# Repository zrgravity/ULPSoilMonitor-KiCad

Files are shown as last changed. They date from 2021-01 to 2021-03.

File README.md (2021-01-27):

# ULPSoilMonitor-KiCad

- Originally created by https://github.com/DerFlob
- See https://blog.m3k.cc/2021/01/ultra-low-power-soil-monitor/
- Original Git Repo: https://cgit.derflob.de/KiCad/ULPSoilMonitor.git
- Arduino source: https://github.com/zrgravity/ULPSoilMonitor-Arduino

Low Power Soil moisture monitor using off-the-shelf moisture sensors and ESP32. OSHW designed in KiCad and software in Arduino.

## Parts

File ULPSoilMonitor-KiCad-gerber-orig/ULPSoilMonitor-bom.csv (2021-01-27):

Comment | Designator | Footprint | LCSC
Battery | BT1 | flobs-KiCad-footprints:BatteryHolder_BHC-18650-1P-2P
470μF | C1 | Capacitor_SMD:CP_Elec_6.3x7.7 | C335982
22μF | C2 | Capacitor_SMD:C_0805_2012Metric | C45783
100nF | C3,C4,C7,C11,C12 | Capacitor_SMD:C_0805_2012Metric | C49678
4.7μF | C5,C6 | Capacitor_SMD:C_0805_2012Metric | C1779
47pF | C8,C9 | Capacitor_SMD:C_0805_2012Metric | C14857
CHARGING | D1 | LED_SMD:LED_0805_2012Metric | C84256
TX | D2 | LED_SMD:LED_0805_2012Metric | C84256
RX | D3 | LED_SMD:LED_0805_2012Metric | C2297
Conn_01x03_Male | J1,J2,J3,J4,J5,J6 | Connector_PinHeader_2.54mm:PinHeader_1x03_P2.54mm_Vertical
USB_B_Micro | J7 | Connector_USB:USB_Micro-B_Amphenol_10103594-0001LF_Horizontal
BME280_(GYBMEP) | J8 | Connector_PinHeader_2.54mm:PinHeader_1x04_P2.54mm_Vertical
BC807 | Q1 | Package_TO_SOT_SMD:SOT-23 | C8587
BC817 | Q3 | Package_TO_SOT_SMD:SOT-23 | C118725
MMDT3904 | Q2,Q4 | Package_TO_SOT_SMD:SOT-363_SC-70-6 | C155305
10k | R1,R21,R22 | Resistor_SMD:R_0805_2012Metric | C17414
4k7 | R2,R3 | Resistor_SMD:R_0805_2012Metric | C17673
27R | R19,R20 | Resistor_SMD:R_0805_2012Metric | C17594
1k | R23,R26 | Resistor_SMD:R_0805_2012Metric | C17513
3k9 | R15,R24 | Resistor_SMD:R_0805_2012Metric | C17614
2k37 | R25 | Resistor_SMD:R_0805_2012Metric | C17523
22k1 | R27 | Resistor_SMD:R_0805_2012Metric | C17518
47k5 | R28 | Resistor_SMD:R_0805_2012Metric | C26011
R | R29,R30 | Resistor_SMD:R_0805_2012Metric | C17630
68k | R4,R5,R6,R7,R12,R13,R14 | Resistor_SMD:R_0805_2012Metric | C17801
30k | R8,R9,R10,R11,R16,R17,R18 | Resistor_SMD:R_0805_2012Metric | C17621
RESET | SW1 | Button_Switch_SMD:SW_SPST_FSMSM | C354943
ESP32-WROOM-32 | U1 | RF_Module:ESP32-WROOM-32 | C473012
MCP73123 | U2 | Package_DFN_QFN:DFN-10-1EP_3x3mm_P0.5mm_EP1.65x2.38mm
CP2102N-A01-GQFN28 | U3 | Package_DFN_QFN:QFN-28-1EP_5x5mm_P0.5mm_EP3.35x3.35mm | C105167
BME280 | U4 | Package_LGA:Bosch_LGA-8_2.5x2.5mm_P0.65mm_ClockwisePinNumbering

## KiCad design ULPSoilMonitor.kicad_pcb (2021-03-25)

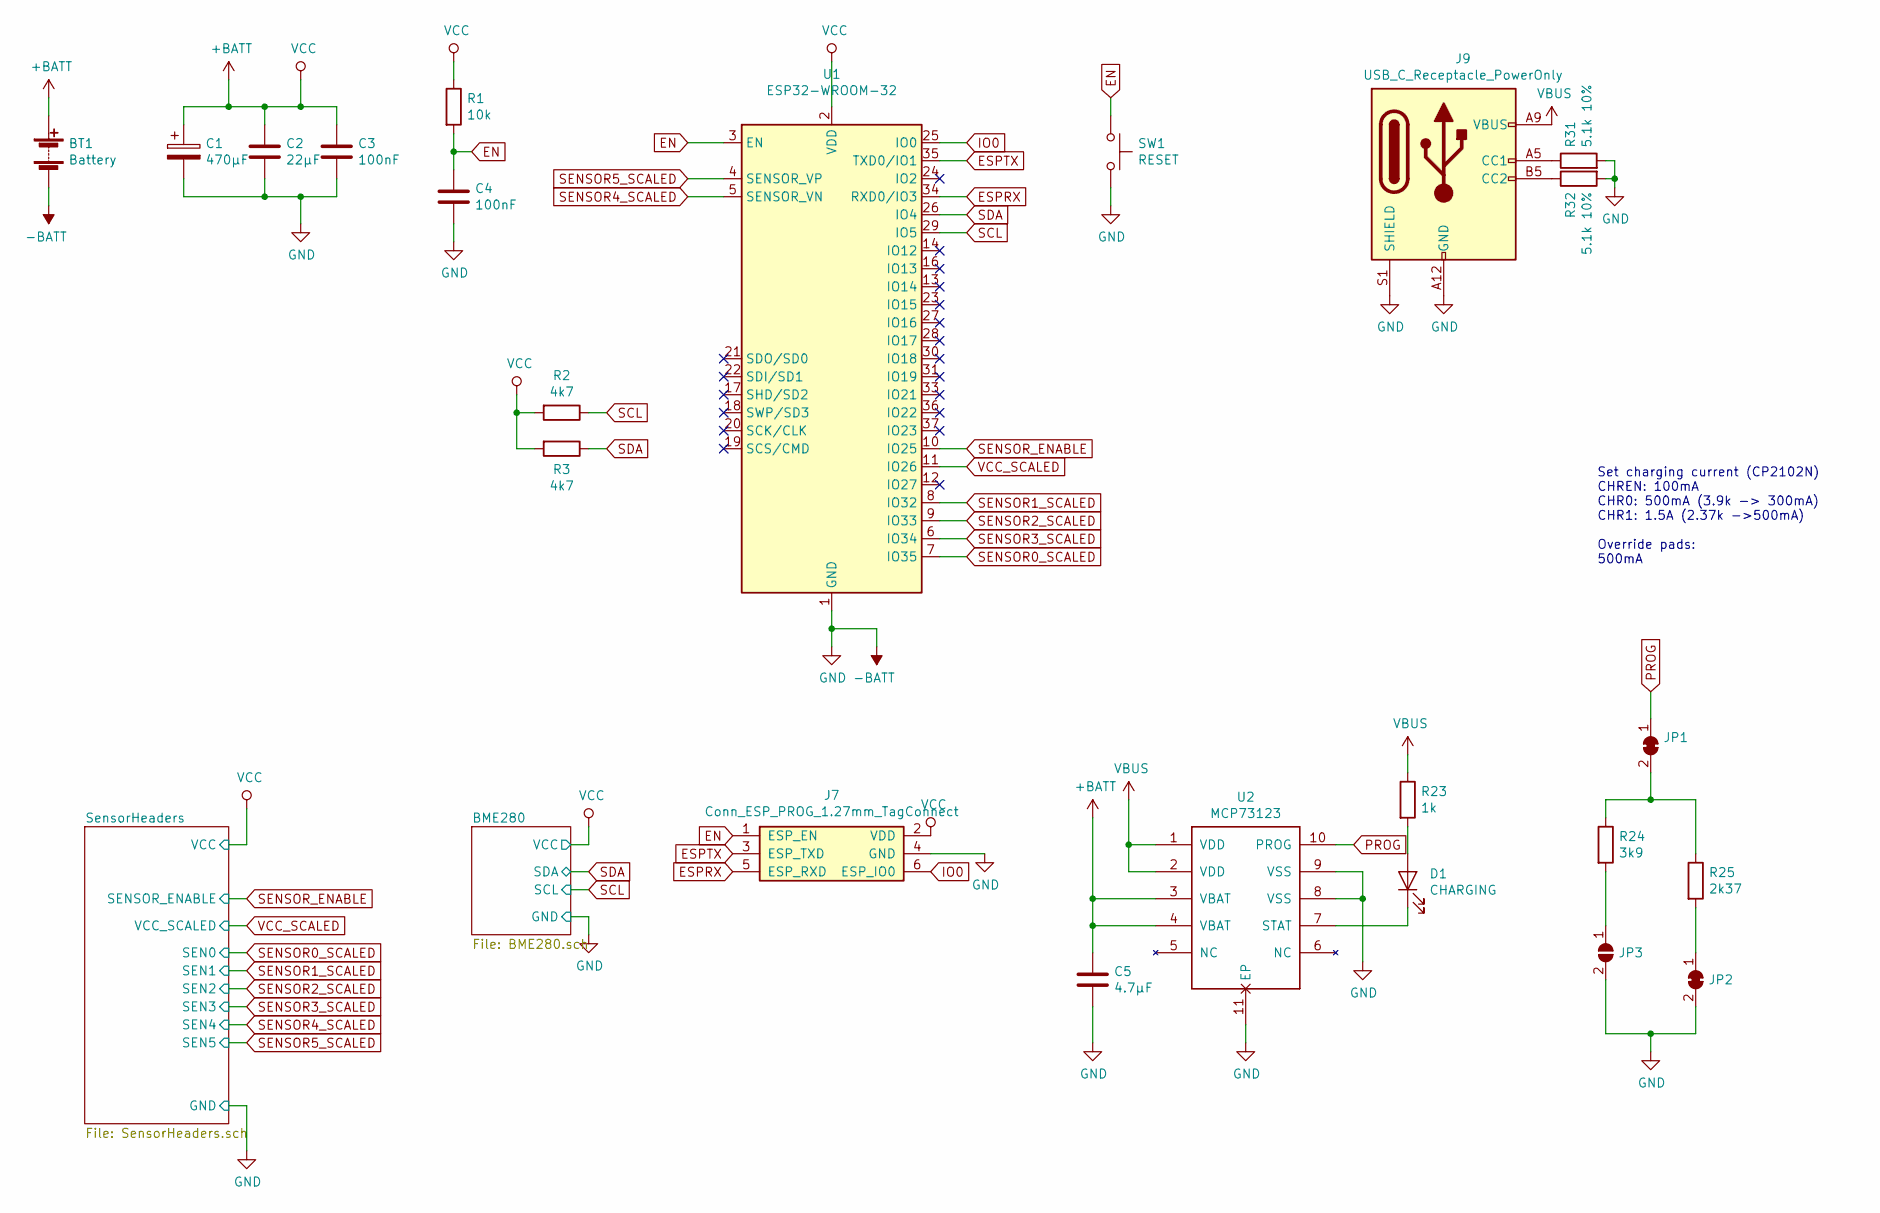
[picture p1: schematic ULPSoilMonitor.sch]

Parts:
BT1: Battery; BatteryHolder_BHC-18650-1P-2P
C1: 470μF; CP_Elec_6.3x7.7; LCSC C335982
C2: 22μF; C_0805_2012Metric; LCSC C45783
C3, C4: 100nF; C_0805_2012Metric; LCSC C49678
C5: 4.7μF; C_0805_2012Metric; LCSC C1779
D1: CHARGING; LED_0805_2012Metric; LCSC C84256
J7: Conn_ESP_PROG_1.27mm_TagConnect; Tag-Connect_TC2030-IDC-NL_2x03_P1.27mm_Vertical
J9: USB_C_Receptacle_PowerOnly; TYPE-C-31-M-17.kicad_mod
JP1: Charg_enable; SolderJumper-2_P1.3mm_Bridged_RoundedPad1.0x1.5mm
JP2: Charge_500mA; SolderJumper-2_P1.3mm_Bridged_RoundedPad1.0x1.5mm
JP3: Charge_300mA; SolderJumper-2_P1.3mm_Open_RoundedPad1.0x1.5mm
R1: 10k; R_0805_2012Metric; LCSC C17414
R2, R3: 4k7; R_0805_2012Metric; LCSC C17673
R23: 1k; R_0805_2012Metric; LCSC C17513
R24: 3k9; R_0805_2012Metric; LCSC C17614
R25: 2k37; R_0805_2012Metric; LCSC C17523
R31, R32: 5.1k 10%; R_0805_2012Metric; LCSC C17513
SW1: RESET; SW_SPST_FSMSM; LCSC C354943
U1: ESP32-WROOM-32; LCSC C473012
U2: MCP73123; DFN-10-1EP_3x3mm_P0.5mm_EP1.65x2.38mm

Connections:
+BATT: BT1.1 (+), C1.1, C2.1, C3.1, C5.1, J7.2 (VDD), R1.1, R2.2, R3.2, U1.2 (VDD), U2.3 (VBAT), U2.4 (VBAT); also elsewhere on the board
-BATT: BT1.2 (-), C1.2, C2.2, C3.2, C4.2, C5.2, J7.4 (GND), J9.A12 (GND), J9.B12 (GND), J9.S1 (SHIELD), JP2.2 (B), JP3.2 (B), R31.2, R32.2, SW1.2, U1.1 (GND), U1.15 (GND), U1.38 (GND), U1.39 (GND), U2.8 (VSS), U2.9 (VSS), U2.11 (EP); also elsewhere on the board
EN: C4.1, J7.1 (ESP_EN), R1.2, SW1.1, U1.3 (EN)
ESPRX: J7.5 (ESP_RXD), U1.34 (RXD0/IO3)
ESPTX: J7.3 (ESP_TXD), U1.35 (TXD0/IO1)
IO0: J7.6 (ESP_IO0), U1.25 (IO0)
unnamed: D1.1 (K), U2.7 (STAT)
unnamed: D1.2 (A), R23.2
unnamed: J9.A5 (CC1), R31.1
unnamed: J9.B5 (CC2), R32.1
unnamed: JP1.2 (B), R24.1, R25.1
unnamed: JP2.1 (A), R25.2
unnamed: JP3.1 (A), R24.2
PROG: JP1.1 (A), U2.10 (PROG)
SCL: R2.1, U1.29 (IO5); also elsewhere on the board
SDA: R3.1, U1.26 (IO4); also elsewhere on the board
SENSOR0_SCALED: U1.7 (IO35); also elsewhere on the board
SENSOR1_SCALED: U1.8 (IO32); also elsewhere on the board
SENSOR2_SCALED: U1.9 (IO33); also elsewhere on the board
SENSOR3_SCALED: U1.6 (IO34); also elsewhere on the board
SENSOR4_SCALED: U1.5 (SENSOR_VN); also elsewhere on the board
SENSOR5_SCALED: U1.4 (SENSOR_VP); also elsewhere on the board
SENSOR_ENABLE: U1.10 (IO25); also elsewhere on the board
VBUS: J9.A9 (VBUS), J9.B9 (VBUS), R23.1, U2.1 (VDD), U2.2 (VDD)
VCC_SCALED: U1.11 (IO26); also elsewhere on the board

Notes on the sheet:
Set charging current (CP2102N) CHREN: 100mA CHR0: 500mA (3.9k -> 300mA) CHR1: 1.5A (2.37k ->500mA) Override pads: 500mA

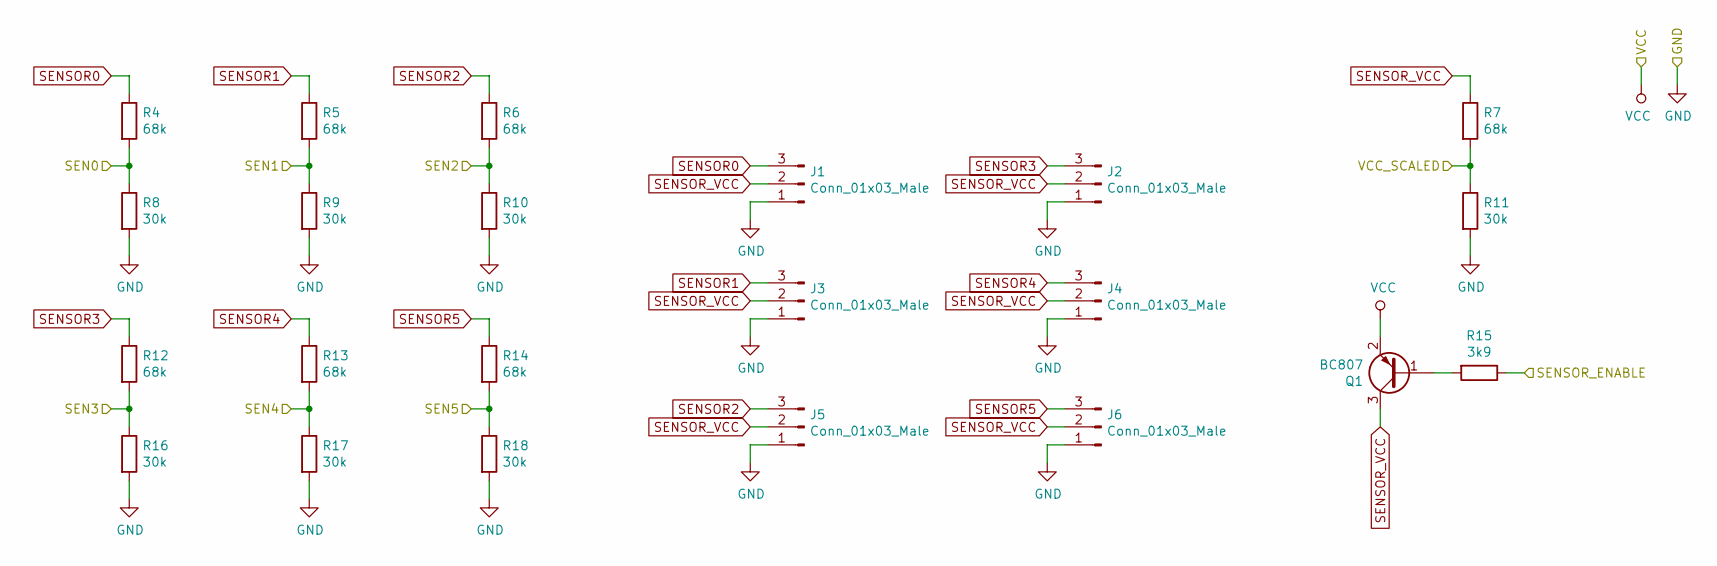
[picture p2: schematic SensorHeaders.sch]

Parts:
J1, J2, J3, J4, J5, J6: Conn_01x03_Male; PinHeader_1x03_P2.54mm_Vertical
Q1: BC807; SOT-23; LCSC C8587
R4, R5, R6, R7, R12, R13, R14: 68k; R_0805_2012Metric; LCSC C17801
R8, R9, R10, R11, R16, R17, R18: 30k; R_0805_2012Metric; LCSC C17621
R15: 3k9; R_0805_2012Metric; LCSC C17614

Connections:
+BATT: Q1.2 (E); also elsewhere on the board
-BATT: J1.1, J2.1, J3.1, J4.1, J5.1, J6.1, R8.2, R9.2, R10.2, R11.2, R16.2, R17.2, R18.2; also elsewhere on the board
unnamed: Q1.1 (B), R15.2
SENSOR0: J1.3, R4.1
SENSOR0_SCALED: R4.2, R8.1; also elsewhere on the board
SENSOR1: J3.3, R5.1
SENSOR1_SCALED: R5.2, R9.1; also elsewhere on the board
SENSOR2: J5.3, R6.1
SENSOR2_SCALED: R6.2, R10.1; also elsewhere on the board
SENSOR3: J2.3, R12.1
SENSOR3_SCALED: R12.2, R16.1; also elsewhere on the board
SENSOR4: J4.3, R13.1
SENSOR4_SCALED: R13.2, R17.1; also elsewhere on the board
SENSOR5: J6.3, R14.1
SENSOR5_SCALED: R14.2, R18.1; also elsewhere on the board
SENSOR_ENABLE: R15.1; also elsewhere on the board
SENSOR_VCC: J1.2, J2.2, J3.2, J4.2, J5.2, J6.2, Q1.3 (C), R7.1
VCC_SCALED: R7.2, R11.1; also elsewhere on the board

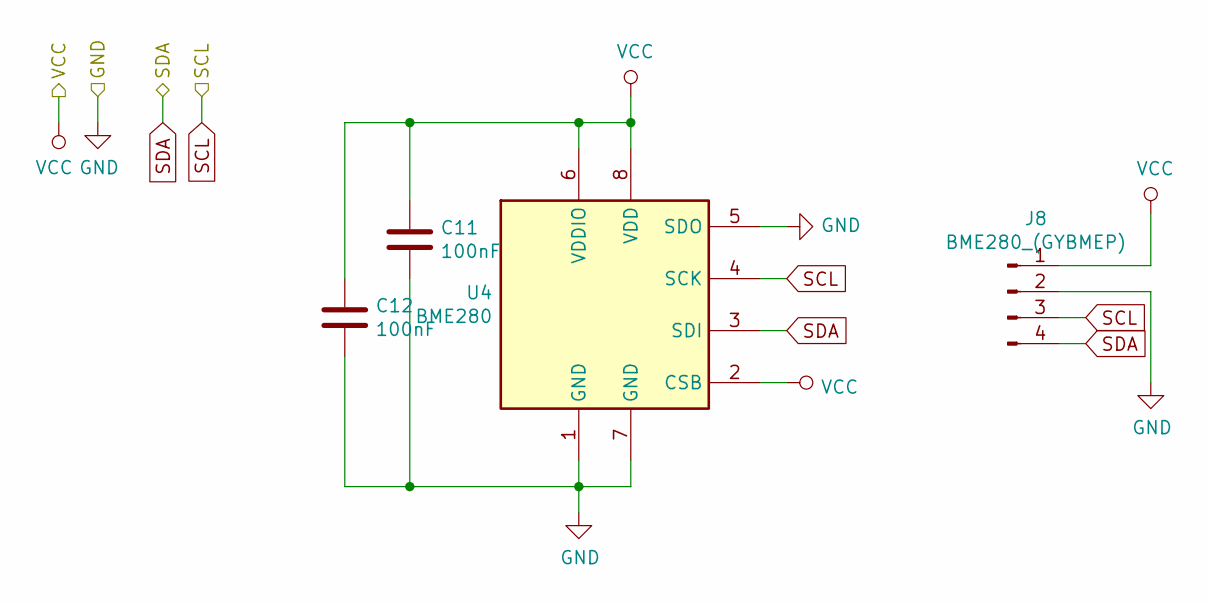
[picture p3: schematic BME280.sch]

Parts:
C11, C12: 100nF; C_0805_2012Metric; LCSC C49678
J8: BME280_(GYBMEP); PinHeader_1x04_P2.54mm_Vertical
U4: BME280; Bosch_LGA-8_2.5x2.5mm_P0.65mm_ClockwisePinNumbering

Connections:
+BATT: C11.1, C12.1, J8.1, U4.2 (CSB), U4.6 (VDDIO), U4.8 (VDD); also elsewhere on the board
-BATT: C11.2, C12.2, J8.2, U4.1 (GND), U4.5 (SDO), U4.7 (GND); also elsewhere on the board
SCL: J8.3, U4.4 (SCK); also elsewhere on the board
SDA: J8.4, U4.3 (SDI); also elsewhere on the board

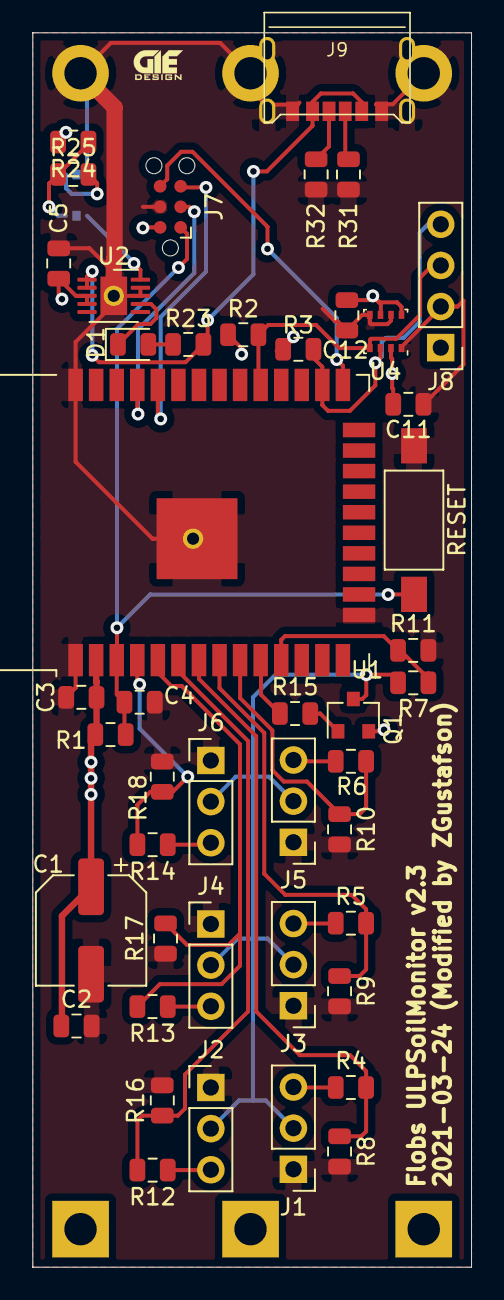
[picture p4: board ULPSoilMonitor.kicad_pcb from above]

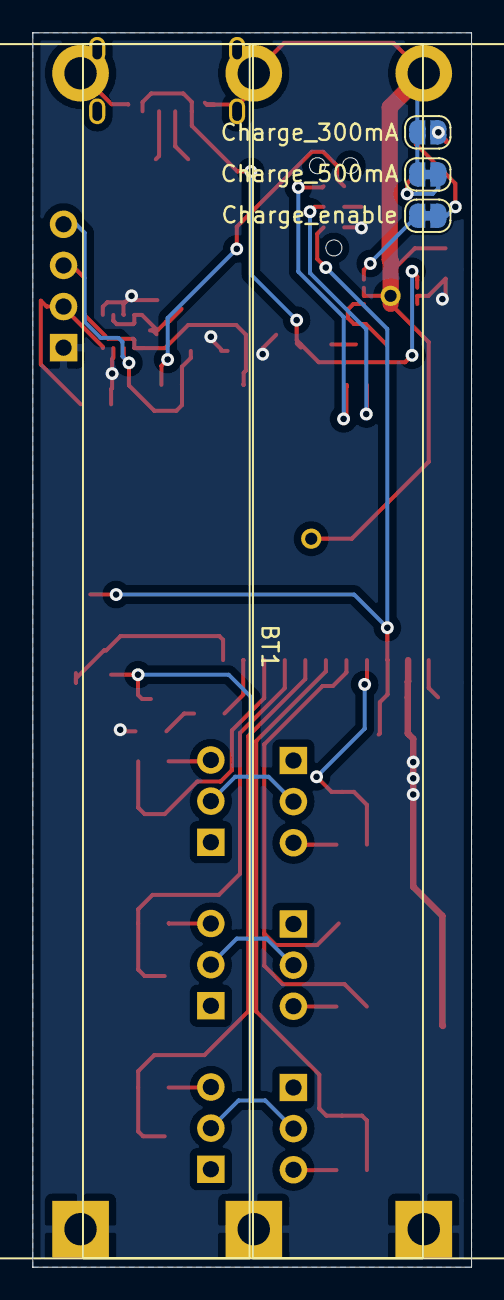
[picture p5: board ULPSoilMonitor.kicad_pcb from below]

Board: 2 copper layers, 27.1 x 76.2 mm, 49 parts (4 on the bottom side), 33 nets.

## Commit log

2020-04-26 ESP32-based soil moisture sensor
    [ULPSoilMonitor.kicad_pcb, ULPSoilMonitor.sch]
2020-05-06 fix cap unit of measure
    [ULPSoilMonitor.sch]
2020-05-16 update to use 18650 LiFePO4 cells
    * connectors for one or two 18650 cells
    * jumper to switch between battery & USB power
    * add optional BME380
    * reset push button
    * more caps
    [BME280.sch, ESPReset.sch, SensorHeaders.sch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]
2020-06-13 add additional spacing between sensor connectors
    [ULPSoilMonitor.kicad_pcb]
2020-06-14 move USB connector further over the edge
    [ULPSoilMonitor.kicad_pcb]
2020-06-23 change USB to Serial chip, support charging
    * exchanges FTDI FT231X for SILabs CP2102N
    * adds MicroChip MCP73123 for LiFePO4 charging
    [ESPReset.sch, ULPSoilMonitor.sch, USBtoSerial.sch]
2020-06-26 update drawing to 882a528a10f6fb48f6454efd446c1280f51ad1f8
    [BME280.sch, ULPSoilMonitor.kicad_pcb, ULPSoilMonitor.sch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]
2020-07-05 route around vias for soldering
    [ULPSoilMonitor.kicad_pcb]
2020-07-05 minor layout adjustments
    [ULPSoilMonitor.kicad_pcb]
2020-07-05 remove unused text
    [ULPSoilMonitor.kicad_pcb]
2020-07-05 update version
    [ULPSoilMonitor.kicad_pcb]
2021-01-27 Add JCLPCB/LCSC part numbers
    [BME280.sch, ESPReset.sch, SensorHeaders.sch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]
2021-01-27 Add gerber and assembly files for original design
    [ULPSoilMonitor-B_Cu.gbr, ULPSoilMonitor-B_Mask.gbr, ULPSoilMonitor-B_Paste.gbr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]
2021-03-24 Set USB-serial DNP
    Disable USB-serial
    Add switches for LiFePo charger PROG setting
    [ESPReset.sch, ULPSoilMonitor.sch, USBtoSerial.sch]
2021-03-24 Update jumper names
    [ULPSoilMonitor.sch]
2021-03-24 Layout jumpers on PCB
    [ULPSoilMonitor.kicad_pcb]
2021-03-24 Add .gitignore for KiCad
2021-03-24 Add USB-C connector
    [ULPSoilMonitor.sch]
2021-03-24 DNP micro-usb
    [USBtoSerial.sch]
2021-03-24 Set charge current to 500mA
    [ULPSoilMonitor.sch]
2021-03-24 Remove USB-mini connector
    [USBtoSerial.sch]
2021-03-24 Remove USB-serial converter
    [BME280.sch, SensorHeaders.sch, ULPSoilMonitor.sch]
2021-03-24 Add Tag-Connect for programming
    [ULPSoilMonitor.sch]
2021-03-24 Fix ERC component errors
    [BME280.sch]
2021-03-24 Edit silkscreen
    [ULPSoilMonitor.kicad_pcb]
